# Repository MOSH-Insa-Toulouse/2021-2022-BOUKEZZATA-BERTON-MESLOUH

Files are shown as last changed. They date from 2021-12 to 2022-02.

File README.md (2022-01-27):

# 2021-2022-BOUKEZZATA-BERTON-MESLOUH

<!--
*** Thanks for checking out the Best-README-Template. If you have a suggestion
*** that would make this better, please fork the repo and create a pull request
*** or simply open an issue with the tag "enhancement".
*** Don't forget to give the project a star!
*** Thanks again! Now go create something AMAZING! :D
-->

<!-- PROJECT SHIELDS -->
<!--
*** I'm using markdown "reference style" links for readability.
*** Reference links are enclosed in brackets [ ] instead of parentheses ( ).
*** See the bottom of this document for the declaration of the reference variables
*** for contributors-url, forks-url, etc. This is an optional, concise syntax you may use.
*** https://www.markdownguide.org/basic-syntax/#reference-style-links
-->
<!-- PROJECT LOGO -->
<br />
<div align="center">
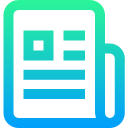
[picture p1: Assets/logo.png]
  
  <h3 align="center">Smart Device</h3>
</div>

<!-- TABLE OF CONTENTS -->
<details>
  <summary>Table of Contents</summary>
  <ol>
    <li>
      <a href="#about-the-project">About The Project</a>
    </li>
    <li>
      <a href="#lora">Lora</a>
    </li>
    <li>
      <a href="#lorawan">LoRAWAN</a>
    </li>
    <li><a href="#kicad">KiCAD</a></li>
    <li><a href="#node-red">Node-Red</a></li>
    <li><a href="#datasheet">DATASHEET</a></li>
  </ol>
</details>

<!-- ABOUT THE PROJECT -->
## About The Project
After manufacturing the gas sensor, we would like to design a system from an ESP32 microcontroller to retrieve the data collected from the sensor and communicate the detection of a specefic gas towards a server with a LoRA module

<p align="right">(<a href="#top">back to top</a>)</p>

<!-- GETTING STARTED -->
## LoRA

We used the <a href="https://github.com/jpmeijers/RN2483-Arduino-Library.git"> RN2483@jpmeijers </a> library to connect the Lora module to the TTN server "The Things Network".

We've connected the 3 pins of the LoRA module to the ESP32
<br/>
```cpp
#define RST 21 //Pin de reset du module LORA
#define RX 18  //Pin RX du module LORA
#define TX 19  //Pin TX du module LORA
```
And We used the serial port 2 (baud 57600) of the ESP32 to communicate with the RN2483
```cpp
rn2xx3 lora(Serial2);
```
To use the simple radio communication. you have to send with the serial monitor connected to your PC this commande (`radio tx "hexa_msg"`)
schema
<br/>
To receive radio communication, you only have to listene on the serail port 2
All the RN2483 command lines end with "\r\n"

```cpp
void initialize_radio()
{
  pinMode(RESET, OUTPUT);
  digitalWrite(RESET, LOW);
  delay(100);
  digitalWrite(RESET, HIGH); //reset the RN2483

  delay(100); //wait for the RN2xx3's startup message
  Serial2.flush();
}

void setup()
{
  Serial.begin(9600);
  Serial2.begin(57600, SERIAL_8N1, RXD2, TXD2);
  initialize_radio();
  Serial.println(Serial2.readStringUntil('\n'));
  Serial2.print("radio set pwr 14\r\n");
  Serial.println(Serial2.readStringUntil('\n'));
  Serial2.print("mac pause\r\n");
  Serial.println(Serial2.readStringUntil('\n'));
}

void loop()
{
  if(Serial2.available()) {
    Serial.println(Serial2.readStringUntil('\n'));
  }
  if (Serial.available())
  { 
    String Command = Serial.readStringUntil('\n');
    Serial.println(Command);
    Serial2.print(Command + "\r\n");
  }
}
```

## LoRAWAN

To connect to the TTN server, you have to copy past the UEI key of the RN2483 with this command (` sys get hwuei `) to this line

```ccp
String AppEUI = "44E53245F1200CDEEC2525661C76BA38"; //AppEUI du reseau sur TTN
```
Then initialze the LoRAWAN module

```cpp
void initialize_LoRAWAN();
```

## KiCAD

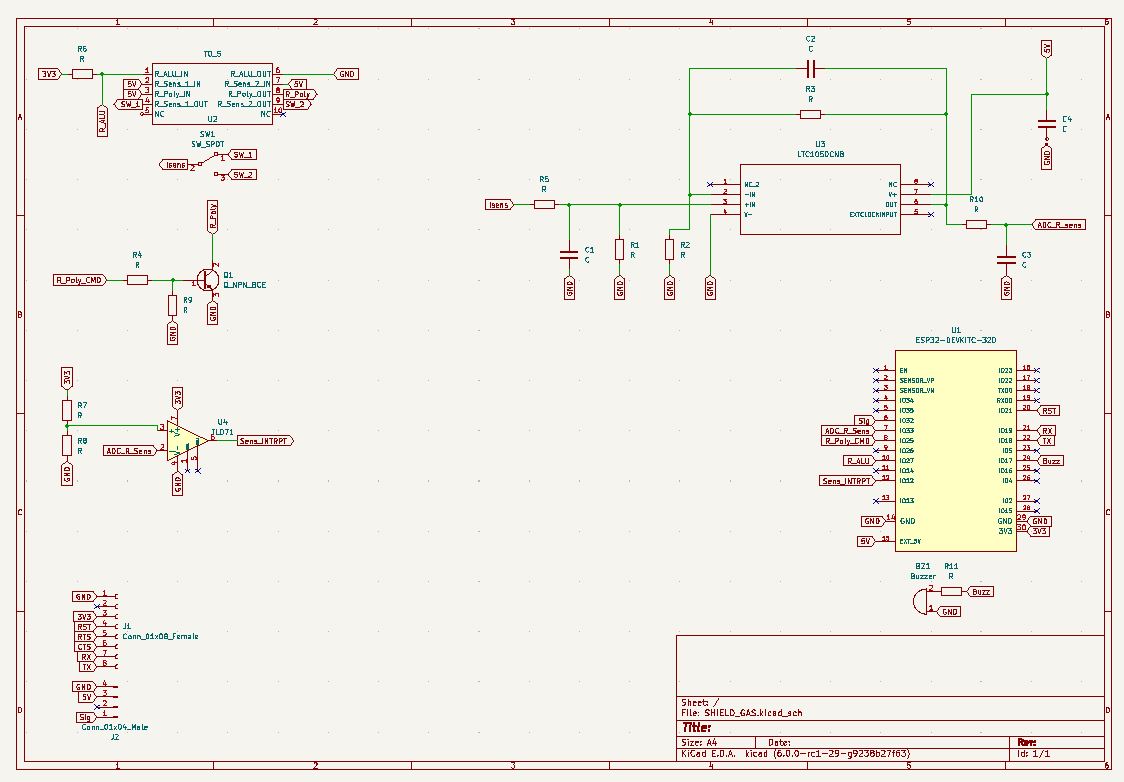
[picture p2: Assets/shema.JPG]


* The sensors are connected to an SPDT switch to commute between the two of them
* The resistor R6 is required to obtain the value of R_Alu.

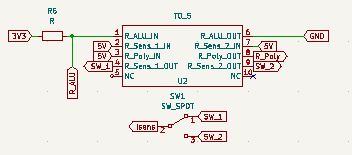
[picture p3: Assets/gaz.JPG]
GAZ


* The operational amplifier (LTC1050) is used to filter and amplify the current passing through the sensors' resistance
* The amplifier must have a low offset votage
* To read the value of the gas sensor you ave to use this command 
```cpp
uint32_t read_aime_sensor () //Recuperation de la donnée du capteur AIME
{
  int sensor_aime_Value = analogRead(ADC_SENS);
  sensor_aime_volt=(float)sensor_aime_Value/4096*V3_3;
  float R_capteur=(1+R3/R2)*R1*V3_3/sensor_aime_volt-R1-R5; //formule justifiée en TD
  return R_capteur;
}
```
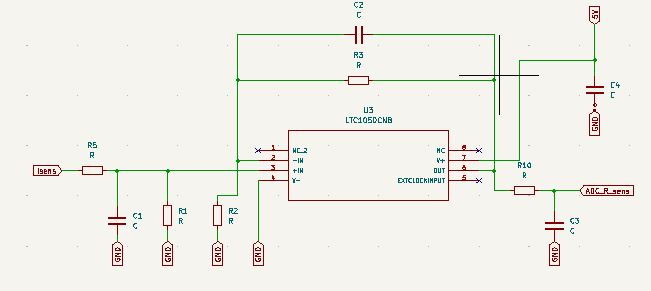
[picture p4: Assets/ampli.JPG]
ampli


* The gas sensor works at least at a temperature of 200°C, so we control the R_poly heater with a PWM from the ESP32, and correct the system error with a PID.
* the resistor R4 is to define the current of the transistor surce (`Is = beta * Ib`)
* You have to define (`a`) and (`b`) of the temparture sensor
```cpp
int a; //
int b; // R_aluminium = a * T(Kelvin) + b 

float temperature () // mesure de la temperature du capteur en fonction de R aluminium
{
  float T = a*(read_r_alu()) + b;
  T = T - 273; //conversion en Celcius
  return T;
}

```
---
```cpp
int manage_PID(int consigne, int kp, int ki, int kd) //Correcteur PID pour maintenir la temprature a 200 degrés celcius
{
  int t_2 = micros();
  float delta_t = ((float) (t_2 - t_1))/1E6
  t_1 = t_2;

  e_t = consigne - temperature();
  e_integral = e_integral + e_t * delta_t; 
  float e_D = (e_t - e_t_1) / (delta_t);
  uint8_t C = kp*e_t + ki*e_integral + kd*e_D;

  t_2 = t_1;
  e_t_1 = e_t;

  C = fabs(C);

  if(C > 255) C = 255; //Pour borner la correction entre 0 et 255
 
  return C; //Duty cycle de la PWM de commande
}

void Cmd_PWM_Poly(int duty_cycle) //Commande de la resistance de chauffe en PWM
{
  ledcWrite(ledChannel,duty_cyle);
}
```
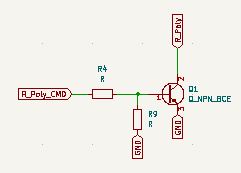
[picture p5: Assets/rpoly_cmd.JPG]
rpoly


* The comparator (LT071) is used to release an interrupt on the ESP32 when the sensor detect a certain gas
* We have defined a refrence voltage on the V+ whith a volatage divider R7 and R8
* If the sensor detect a gas, the sensor voltage ADC dropdown and the output LT071 will be 1

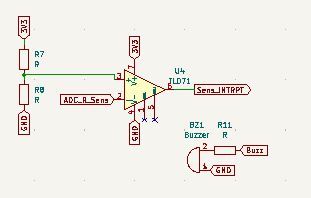
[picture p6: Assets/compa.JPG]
compa


we designed the PCB.

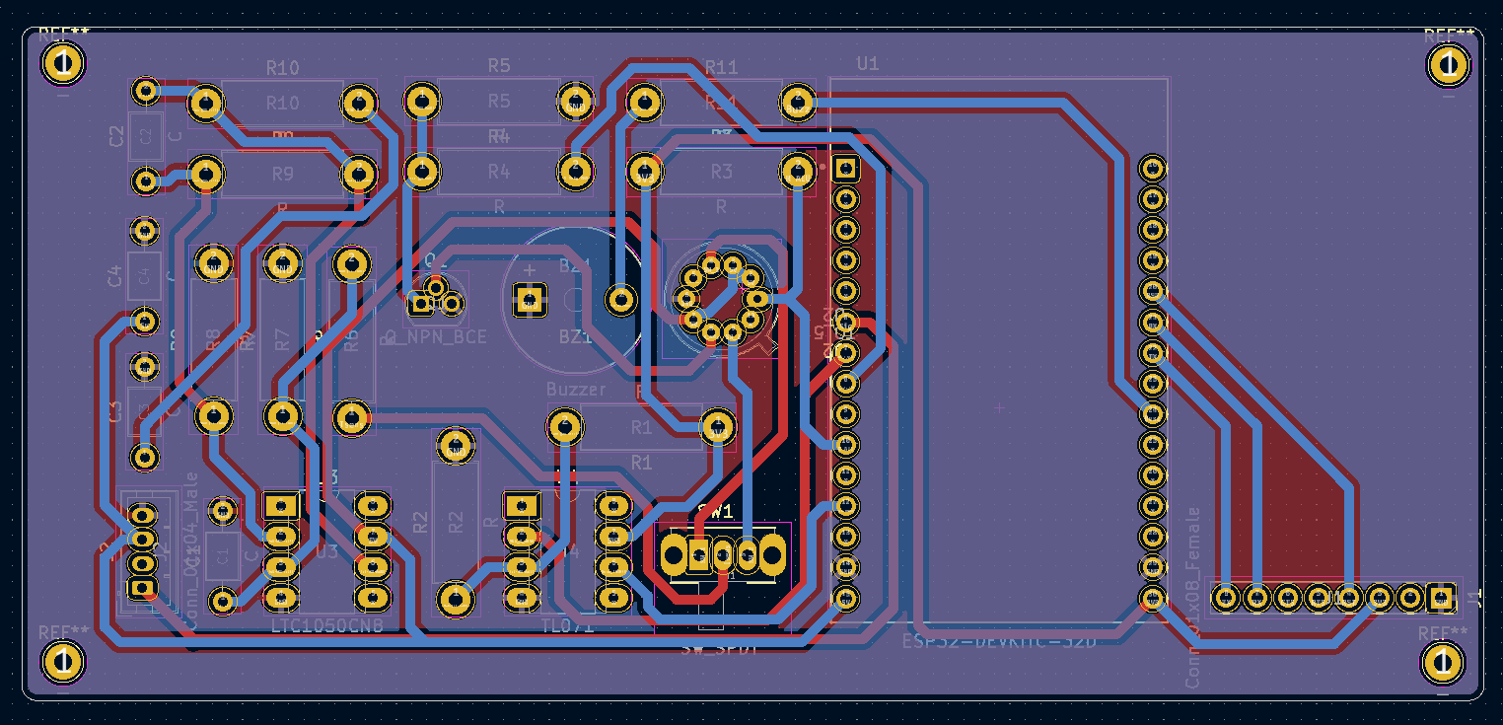
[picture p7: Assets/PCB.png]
PCB


## Node-Red
For the last part, we needed an application to setup the system and a dashboard to display the sensor values. For this, we used Node-red to connect the gas sensor with the TTN server via LORAWAN communication.

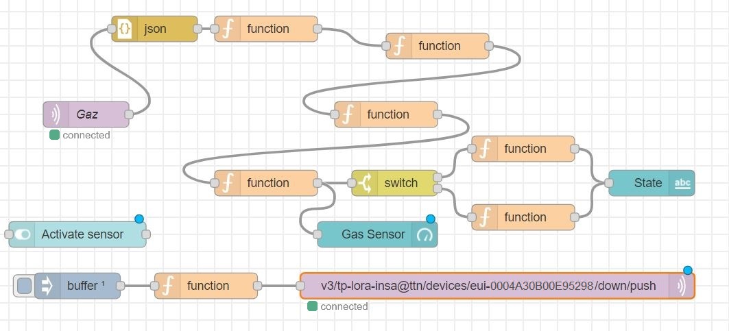
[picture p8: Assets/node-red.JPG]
flows


The dashboard of the system

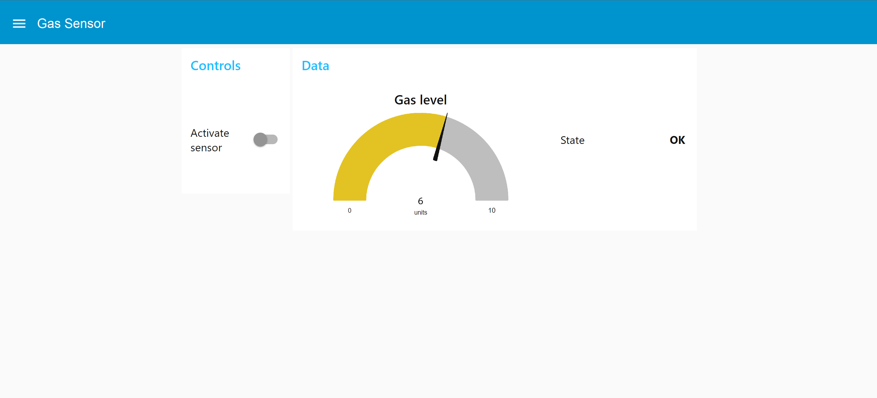
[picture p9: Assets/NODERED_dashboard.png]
dashboard


## DATASHEET

you can find the datasheet <a href="/Assets/Datasheet_AIME_git.pdf" target="_blank"> HERE </a>

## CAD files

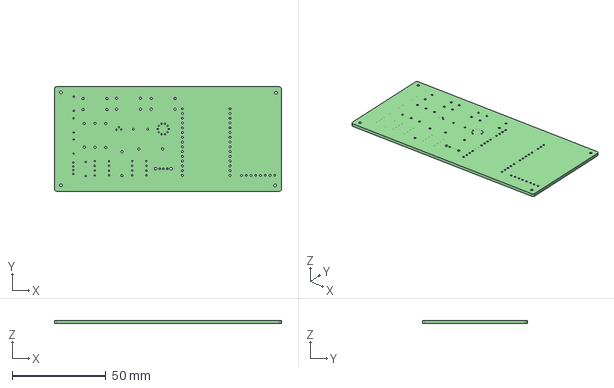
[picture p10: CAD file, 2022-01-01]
KICAD/SHIELD_GAS.step
121.0 x 55.8 x 1.60 mm

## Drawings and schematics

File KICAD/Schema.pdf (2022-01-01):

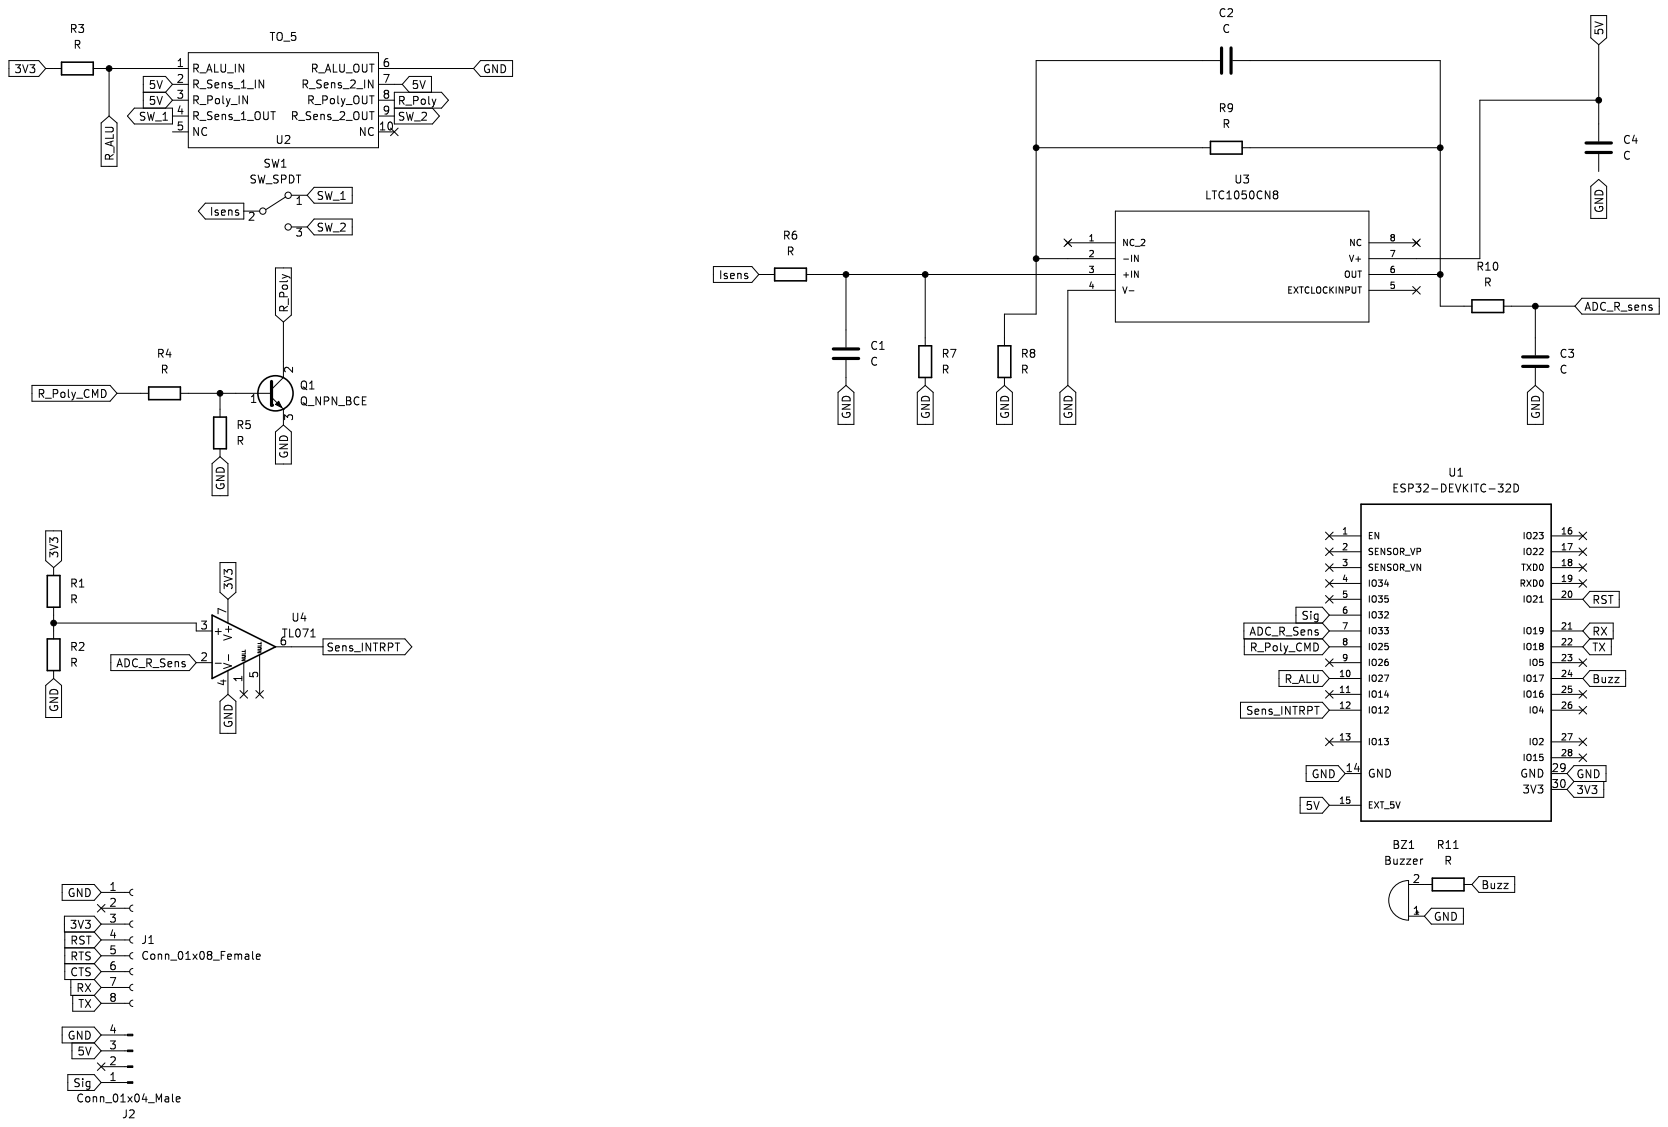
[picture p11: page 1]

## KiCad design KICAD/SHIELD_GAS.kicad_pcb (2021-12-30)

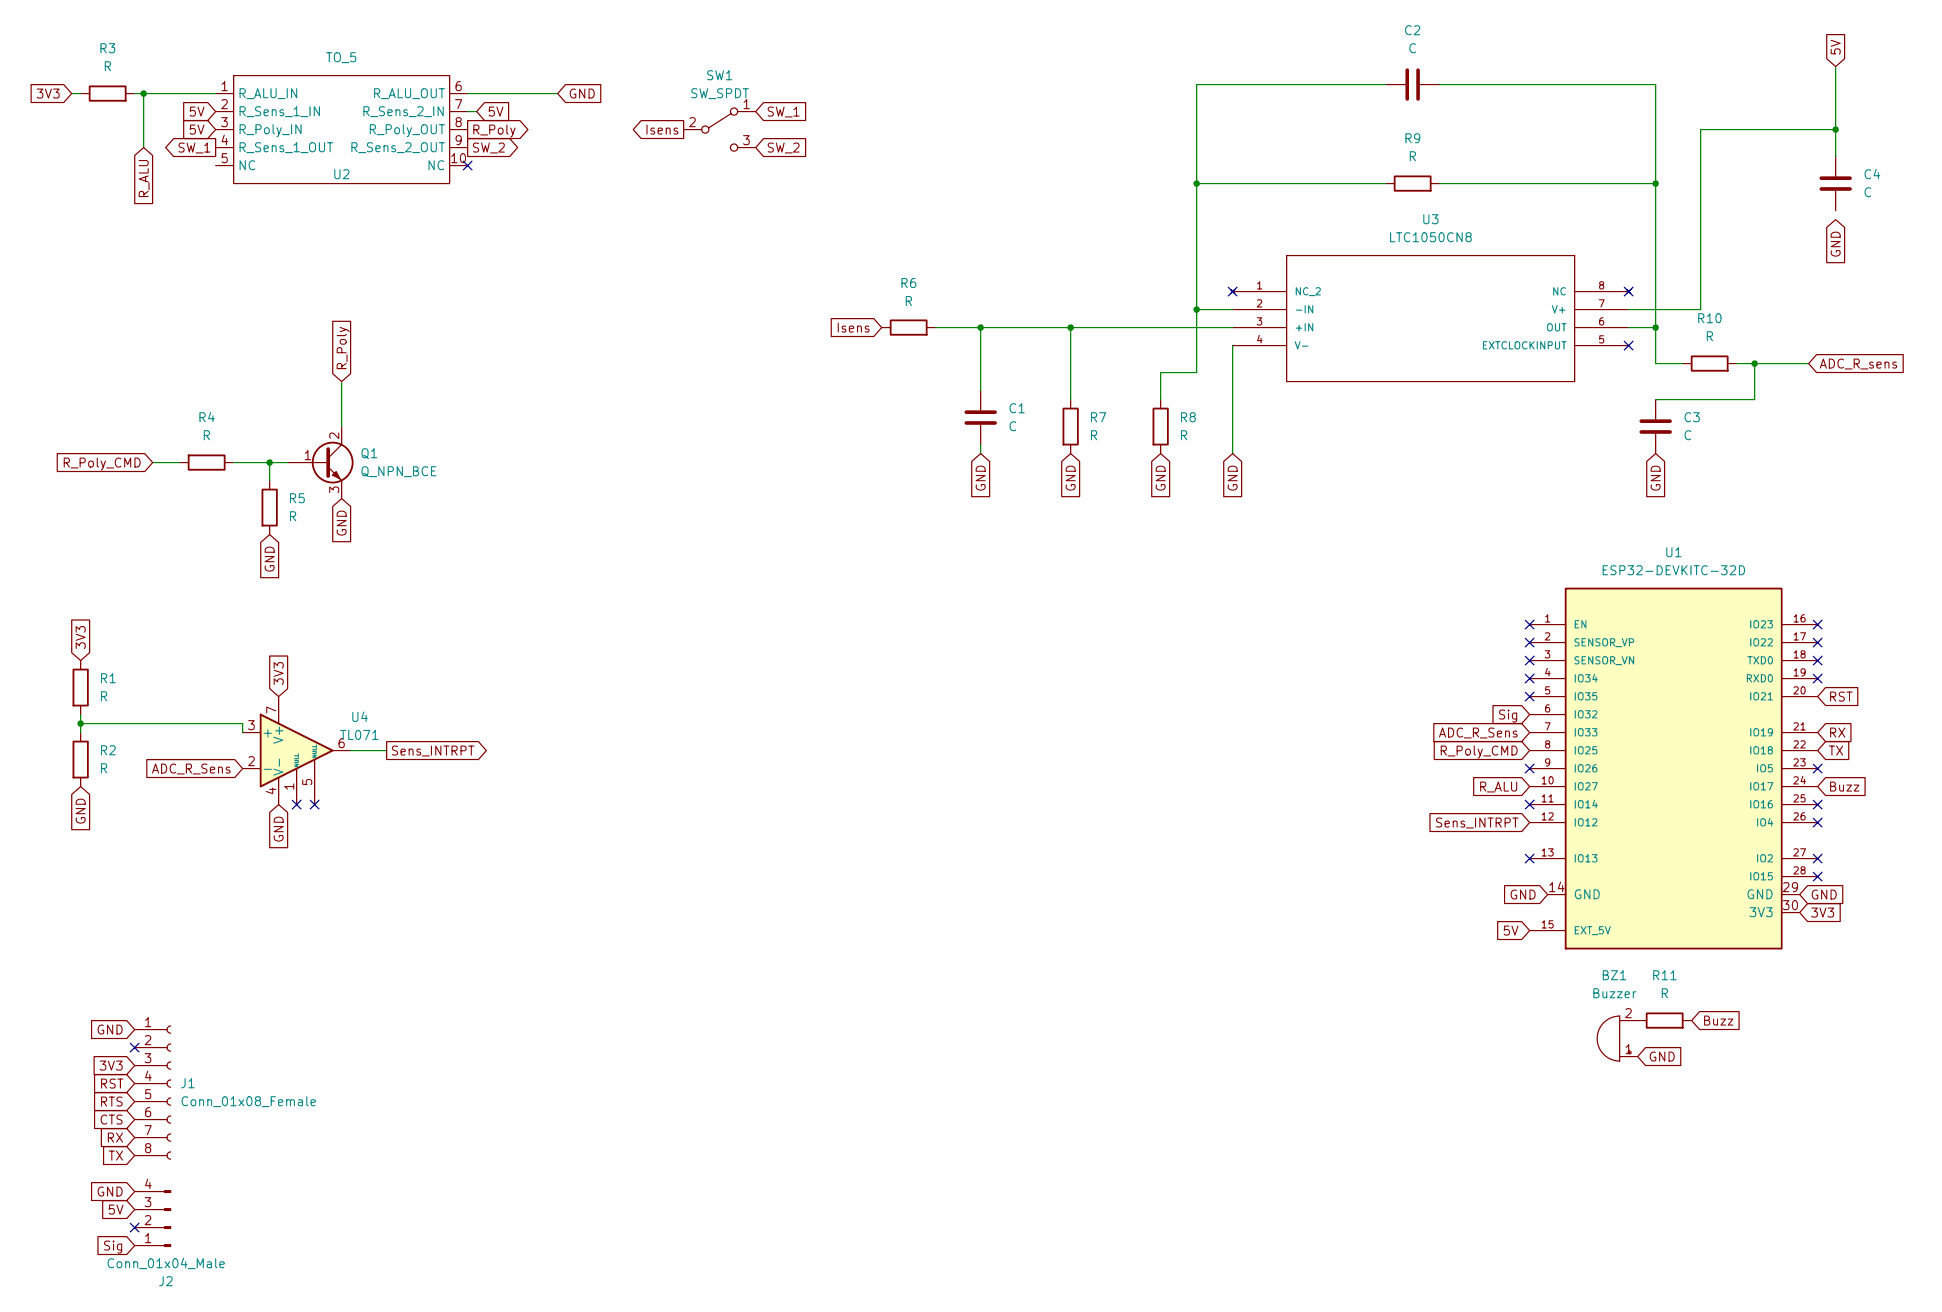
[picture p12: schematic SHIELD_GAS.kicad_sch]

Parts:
BZ1: Buzzer; Buzzer_12x9.5RM7.6
C1, C2, C3, C4: C; C_Axial_L3.8mm_D2.6mm_P7.50mm_Horizontal
J1: Conn_01x08_Female; PinSocket_1x08_P2.54mm_Vertical
J2: Conn_01x04_Male; JST_PH_B4B-PH-K_1x04_P2.00mm_Vertical
Q1: Q_NPN_BCE; TO-92
R1, R2, R3, R4, R5, R6, R7, R8, R9, R10, R11: R; R_Axial_DIN0411_L9.9mm_D3.6mm_P12.70mm_Horizontal
SW1: SW_SPDT; SW_CuK_OS102011MA1QN1_SPDT_Angled
U1: ESP32-DEVKITC-32D; MODULE_ESP32-DEVKITC-32D; PARTREV 4
U2: TO_5; TO-5
U3: LTC1050CN8; DIP-8_W7.62mm_LongPads; MANUFACTURER_PART_NUMBER ltc1050cn8
U4: TL071; DIP-8_W7.62mm_LongPads

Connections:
3V3: J1.3, R1.1, R3.1, U1.30 (3V3), U4.7 (V+)
5V: C4.1, J2.3, U1.15 (EXT_5V), U2.2 (R_Sens_1_IN), U2.3 (R_Poly_IN), U2.7 (R_Sens_2_IN), U3.7 (V+)
ADC_R_Sens: U1.7 (IO33), U4.2 (-)
ADC_R_sens: C3.1, R10.2
Buzz: R11.2, U1.24 (IO17)
CTS: J1.6
GND: BZ1.1 (-), C1.2, C3.2, C4.2, J1.1, J2.4, Q1.3 (E), R2.2, R5.2, R7.2, R8.2, U1.14 (GND), U1.29 (GND), U2.6 (R_ALU_OUT), U3.4 (V-), U4.4 (V-)
Isens: R6.1, SW1.2 (B)
unnamed: BZ1.2 (+), R11.1
unnamed: C1.1, R6.2, R7.1, U3.3 (+IN)
unnamed: C2.1, R8.1, R9.1, U3.2 (-IN)
unnamed: C2.2, R9.2, R10.1, U3.6 (OUT)
unnamed: Q1.1 (B), R4.1, R5.1
unnamed: R1.2, R2.1, U4.3 (+)
RST: J1.4, U1.20 (IO21)
RTS: J1.5
RX: J1.7, U1.21 (IO19)
R_ALU: R3.2, U1.10 (IO27), U2.1 (R_ALU_IN)
R_Poly: Q1.2 (C), U2.8 (R_Poly_OUT)
R_Poly_CMD: R4.2, U1.8 (IO25)
SW_1: SW1.1 (A), U2.4 (R_Sens_1_OUT)
SW_2: SW1.3 (C), U2.9 (R_Sens_2_OUT)
Sens_INTRPT: U1.12 (IO12), U4.6
Sig: J2.1, U1.6 (IO32)
TX: J1.8, U1.22 (IO18)

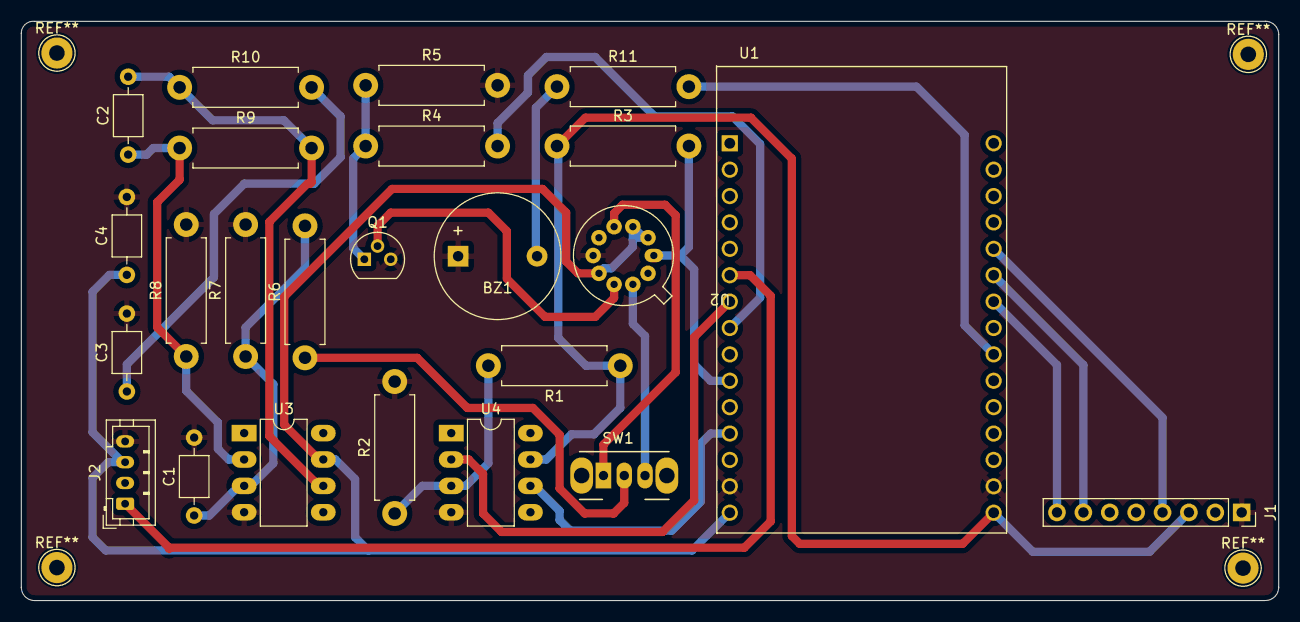
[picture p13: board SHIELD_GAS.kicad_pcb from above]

Board: 2 copper layers, 121.0 x 55.8 mm, 24 parts (0 on the bottom side), 23 nets.

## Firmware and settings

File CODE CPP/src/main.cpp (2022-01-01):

#include <Arduino.h>
#include "rn2xx3.h"

#define RST 21 //Pin de reset du module LORA
#define RX 18  //Pin RX du module LORA
#define TX 19  //Pin TX du module LORA
#define INTERRUPT_PIN 12 //Pin d'interruption du capteur de GAZ
#define SIG_grove 2  //Signal d'entree du capteur grove (industriel)
#define Buzz_pin 17  //Pin de sortie du buzzer
#define R_Poly_CMD 16 //Pin de la sortie de commande de la resistance de chauffe (Polysilicium)
#define ADC_SENS 33 // Pin d'entree du signal du capteur de gaz (AIME)
#define ADC_R_Alu 27 //Pin d'entree de la resistance d'ALUMINIUM (capteur de temperature)

int a; //
int b; // R_aluminium = a * T(Kelvin) + b 
String AppEUI = "44E53245F1200CDEEC2525661C76BA38"; //AppEUI du reseau sur TTN
String AppKey = "0000000000000000"; //AppKey du reseau TTN
rn2xx3 myLora(Serial2); //Constructeur de la classe rn2xx3
byte payload[4]; //Payload a envoyer sur TTN
float R0=0.45; //Resistance du module grove en environement ambiant
float sensor_grove_volt; //conversion en volt de l'entree du signal du capteur grove
float sensor_aime_volt; //conversion en volt de l'entree du signal du capteur AIME
float RS_gas; //recoit la valeur de RS dans le gaz
float ratio; // Get ratio RS_GAS/RS_air
int duty_cyle; //duty cycle du signal PWM pour la commande de la resistance de chauffe
int t_1 = 0; //timestamp 1
int t_2 = 0; //timestamp 2
float e_t = 0; //mesure de l'erreur a t
float e_t_1 = 0; //mesure de l'erreur a t-1
float e_integral= 0  //erreur de l'integral
uint32_t grove_data; //donnée capteur grove
uint32_t aime_data;  //donnée capteur AIME
int R1=1E5; //
int R2=1E3; //
int R3=1E5; //
int R5=1E4;  //Resistances du circuit de conditionnement selon la meme numerotation que dans KICAD !
float V3_3 = 3.3; // A definir en fonction des grandeurs electriques voulues
int R6; //
const uint32_t PWM_OUT = 16;  //Pin de sortie de la commande PWM de la resistance de chauffe
// setup des propriétés PWM
const uint32_t freq = 20000;
const uint32_t ledChannel = 0;
const uint32_t resolution = 8;

void initialize_LoRAWAN() //Initialization du module LORA
{
  //Reset du module
  pinMode(RST, OUTPUT);
  digitalWrite(RST, LOW);
  delay(100);
  digitalWrite(RST, HIGH);
  delay(100); //Attente du message de start du module LORA
  Serial2.flush();
  //check de la communication avec la radio
  String hweui = myLora.hweui();
  while(hweui.length() != 16)
  {
    Serial.println("Communication with RN2xx3 unsuccessful. Power cycle the board.");
    Serial.println(hweui);
    delay(10000);
    hweui = myLora.hweui();
  }
  //Recuperation de HWEUI pour la configurer sur TTN
  Serial.println("When using OTAA, register this DevEUI: ");
  Serial.println(hweui);
  Serial.println("RN2xx3 firmware version:");
  Serial.println(myLora.sysver());
  //message de debug de type "en attente de connexion"
  Serial.println("Trying to join TTN");
  bool join_result = false;
  //OTAA: initOTAA(String AppEUI, String AppKey);
  join_result = myLora.initOTAA(AppEUI, AppKey);
  while(!join_result)
  {
    Serial.println("Unable to join. Are your keys correct, and do you have TTN coverage?");
    delay(60000); //delay d'une minute avant retry 
    join_result = myLora.init();
  }
  Serial.println("Successfully joined TTN");
  }

void manage_interrupt() //gestion de l'interruption du capteur
{
  digitalWrite(Buzz_pin, 1); //active l'alarme a la detection du GAZ (interruption materielle)
  grove_data=read_grove_sensor();
  aime_data=read_aime_sensor();
  payload[0] = highByte(grove_data);
  payload[1] = lowByte(grove_data);
  payload[2]=highByte(aime_data);  
  payload[1]=lowByte(aime_data);
  myLora.txBytes(payload,4); 
}

uint32_t read_grove_sensor () //Recuperation de la donnée du capteur grove
{
  int sensor_groove_Value = analogRead(SIG_grove); 
  sensor_grove_volt=(float)sensor_groove_Value/4096*5.0; //conversion en tention
  RS_gas = (5.0-sensor_grove_volt)/sensor_grove_volt; // TAUX VARIATION RESISTANCE SELON GAZ
  ratio = (RS_gas/R0);  // ratio = RS/R0
  uint32_t data=ratio*100;
  return data;
}

uint32_t read_aime_sensor () //Recuperation de la donnée du capteur AIME
{
  int sensor_aime_Value = analogRead(ADC_SENS);
  sensor_aime_volt=(float)sensor_aime_Value/4096*V3_3;
  float R_capteur=(1+R3/R2)*R1*V3_3/sensor_aime_volt-R1-R5; //formule justifiée en TD
  return R_capteur;
}

uint32_t read_r_alu () //Recuperation de la donnée du capteur de temparateur (R ALU)
{
  int ADC_R_ALU = analogRead(ADC_R_Alu);
  float ADC_R_ALU_volt=(float)ADC_R_Alu/4096*V3_3;
  float R_Alu=ADC_R_ALU_volt*R6/(V3_3-ADC_R_ALU_volt);
  return R_Alu;
}

void config_PWM() // configure des fonctionnalités PWM
{
  ledcSetup(ledChannel, freq, resolution);
  ledcAttachPin(PWM_OUT, ledChannel); //Liaison de la chaine du Timer avec la pin utilisée
}

float temperature () // mesure de la temperature du capteur en fonction de R aluminium
{
  float T = a*(read_r_alu()) + b;
  T = T - 273; //conversion en Celcius
  return T;
}

int manage_PID(int consigne, int kp, int ki, int kd) //Correcteur PID pour maintenir la temprature a 200 degrés celcius
{
  int t_2 = micros();
  float delta_t = ((float) (t_2 - t_1))/1E6
  t_1 = t_2;


  e_t = consigne - temperature();
  e_integral = e_integral + e_t * delta_t; 
  float e_D = (e_t - e_t_1) / (delta_t);
  uint8_t C = kp*e_t + ki*e_integral + kd*e_D;

  t_2 = t_1;
  e_t_1 = e_t;

  C = fabs(C);

  if(C > 255) C = 255; //Pour borner la correction entre 0 et 255
 
  return C; //Duty cycle de la PWM de commande
}

void Cmd_PWM_Poly(int duty_cycle) //Commande de la resistance de chauffe en PWM
{
  ledcWrite(ledChannel,duty_cyle);
}

void setup() {
  Serial.begin(9600); //initialisation moniteur serie (ESP - PC)
  config_PWM(); //configuration de la PWM
  Serial2.begin(57600, SERIAL_8N1, RX, TX); //initialisation moniteur serie 2 (LORA - ESP)
  initialize_LoRAWAN(); //initialiation de la radio
  Serial2.print("sys get hwei\r\n"); // recuperation du HWEUI
  Serial.println(Serial2.readStringUntil('\n'));
  digitalWrite(Buzz_pin, 0); // on initialise le buzzer
  attachInterrupt(INTERRUPT_PIN, manage_interrupt, LOW); //Appel de la fonction d'inerruption
  
}

void loop() {
  int cmd_R_poly = manage_PID(200, 1, 0, 0);
  Cmd_PWM_Poly(cmd_R_poly); 
   
}

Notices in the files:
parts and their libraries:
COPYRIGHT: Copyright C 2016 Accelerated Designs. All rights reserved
